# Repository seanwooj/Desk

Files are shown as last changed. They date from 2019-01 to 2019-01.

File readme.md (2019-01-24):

# Objectives
To make a desk using the CNC knowledge and tactics of OpenDesk
This means:
- Open source
- Modular
- Parametrically designed
- Fabricatable anywhere

# Links
- [Studio Desk](https://www.opendesk.cc/lean/studio-desk#get-it-made)
- [OpenDesk Design Guidelines](https://www.opendesk.cc/playbook/community-resources/designer-onboarding/design-guidelines)
- [OpenDesk Community Forum](https://groups.google.com/forum/#!forum/opendesk-community)
- [Studio Desk Maker Guide](https://github.com/opendesk/design-playground/blob/gh-pages/opendesk-studio-desk/160323_Studio_Desk_Maker_Guide.pdf)
- [OpenDesk Design Playground](https://github.com/opendesk/design-playground/)

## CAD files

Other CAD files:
Studio Desk Files/LEN_STU_PUB_EXP_W-800_L-1600_C-ST_A-SA_M-AP_cad-1_18.000.dxf

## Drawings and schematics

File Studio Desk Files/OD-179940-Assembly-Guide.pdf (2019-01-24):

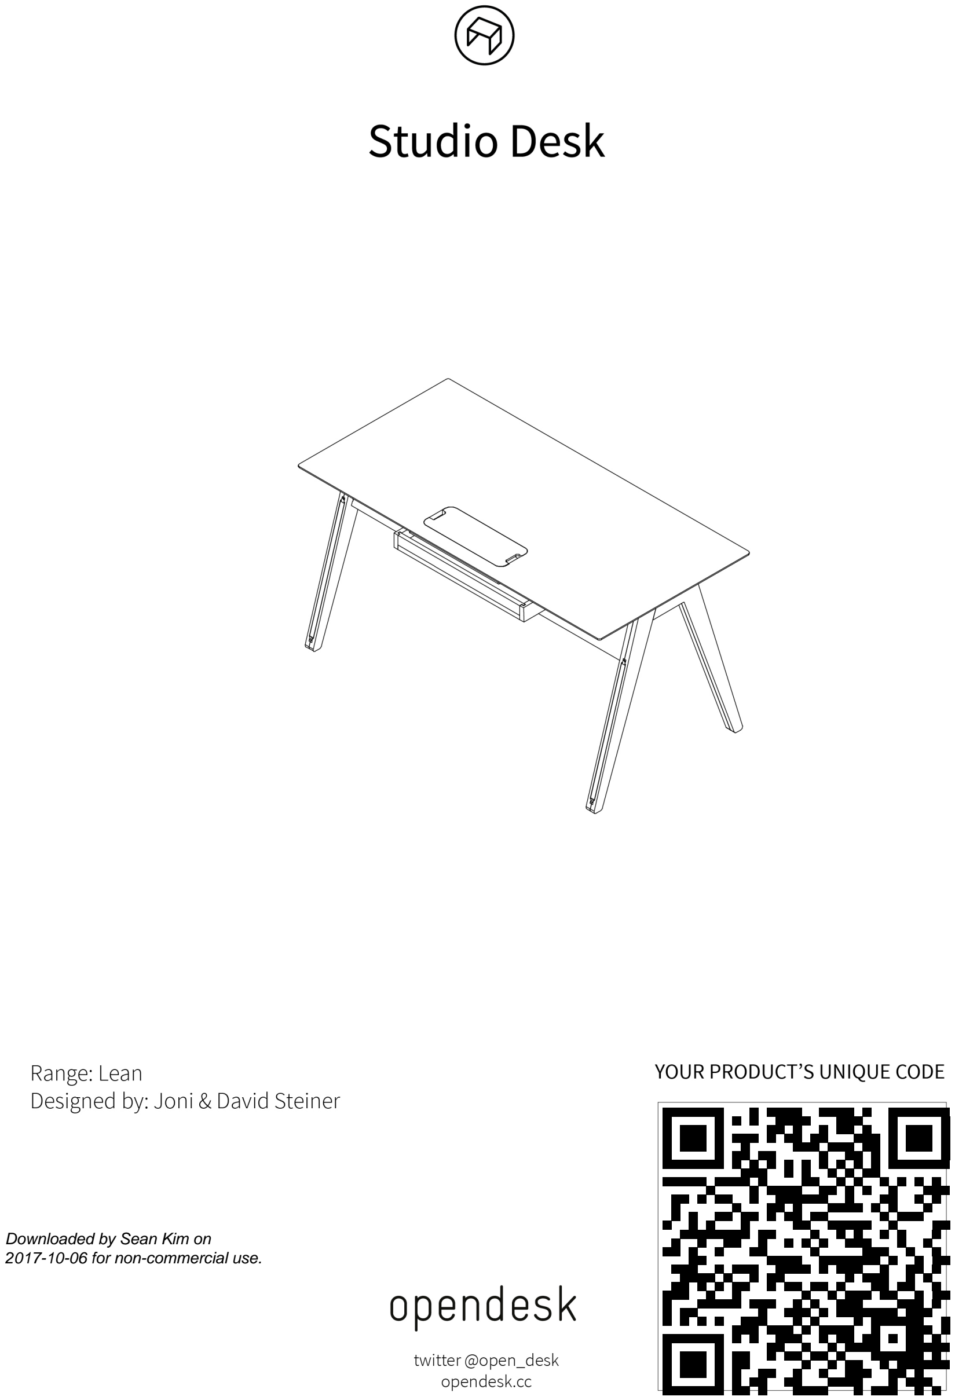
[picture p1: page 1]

Downloaded by Sean Kim on
2017-10-06 for non-commercial use.

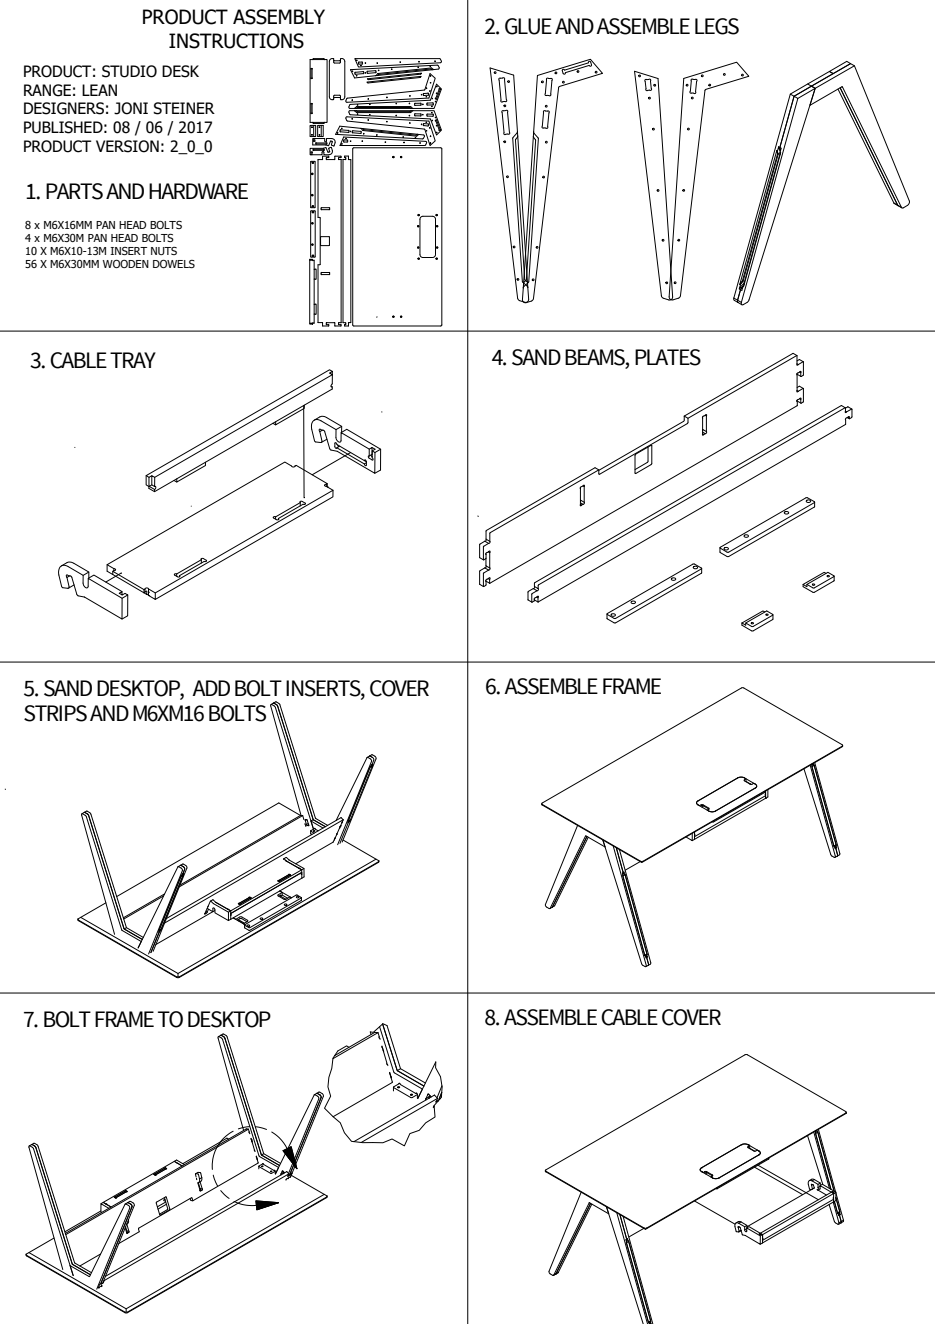
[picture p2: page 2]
2.GLUEANDASSEMBLELEGS; 3. CABLETRAY; 4. SANDBEAMS, PLATES; 5. SANDDESKTOP, ADDBOLTINSERTS, COVER; 6. ASSEMBLEFRAME; STRIPSANDM6XM16BOLTS; 7. BOLTFRAMETODESKTOP; 8. ASSEMBLECABLECOVER; PRODUCT ASSEMBLY INSTRUCTIONS

PRODUCT: STUDIO DESK
RANGE: LEAN
DESIGNERS: JONI STEINER
PUBLISHED: 08 / 06 / 2017
PRODUCT VERSION: 2_0_0
1. PARTSANDHARDWARE

8 x M6X16MM PAN HEAD BOLTS
4 x M6X30M PAN HEAD BOLTS
10 X M6X10-13M INSERT NUTS
56 X M6X30MM WOODEN DOWELS

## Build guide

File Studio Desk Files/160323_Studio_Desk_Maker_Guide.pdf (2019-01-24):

# Studio Desk

# Maker Guide

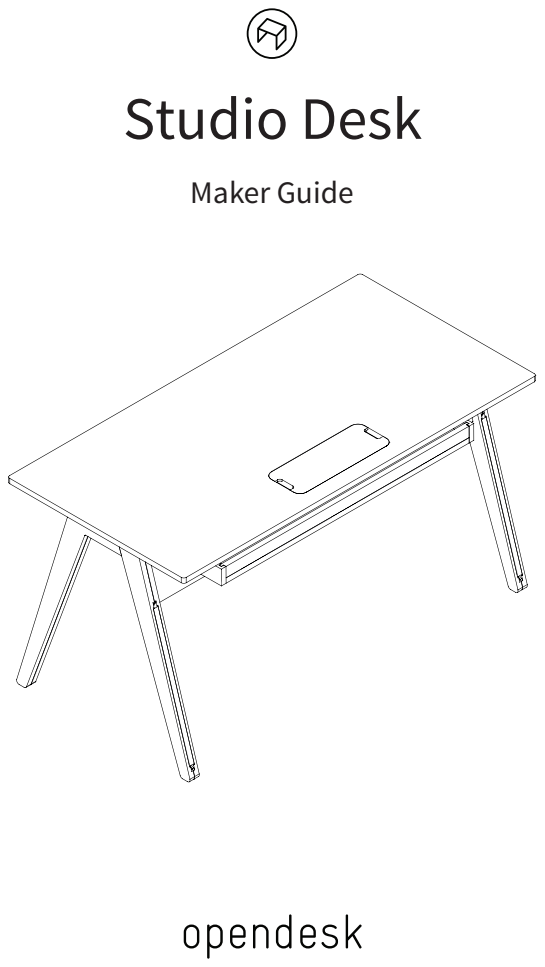
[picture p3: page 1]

# Welcome to your new Opendesk

Every piece of Opendesk furniture is made to order by independent local makers. Opendesk makers produce products on-demand using digital fabricators (CNC- machines) combined with traditional craft skills - working from designs contributed by a global community of designers and hosted on opendesk.cc.

The product you have in your hands is therefore the result of a new model sitting at the union of the internet, new advancements in digital technologies, and age-old making techniques. We call this Open Making.

# Tools

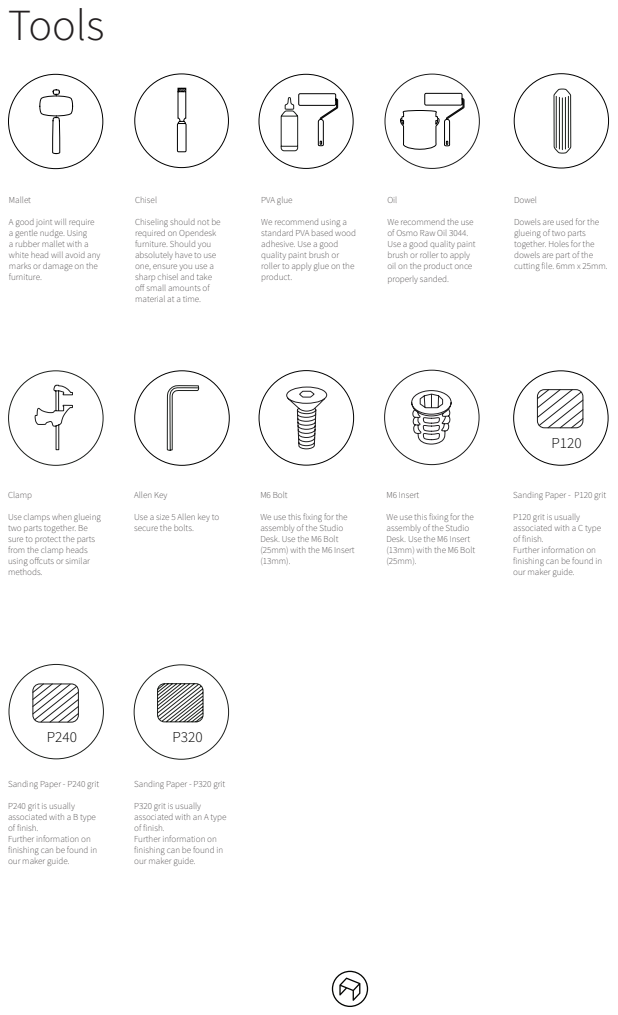
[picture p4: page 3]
Mallet; Chisel; PVA glue; Oil; Dowel; Clamp; Allen Key; M6 Bolt; M6 Insert

A good joint will require
a gentle nudge. Using
a rubber mallet with a
white head will avoid any
marks or damage on the
furniture.

Chiseling should not be
required on Opendesk
furniture. Should you
absolutely have to use
one, ensure you use a
sharp chisel and take
off small amounts of
material at a time.

We recommend using a
standard PVA based wood
adhesive. Use a good
quality paint brush or
roller to apply glue on the
product.

We recommend the use
of Osmo Raw Oil 3044.
Use a good quality paint
brush or roller to apply
oil on the product once
properly sanded.

Dowels are used for the
glueing of two parts
together. Holes for the
dowels are part of the
cutting file. 6mm x 25mm.

Sanding Paper - P120 grit

Use clamps when glueing
two parts together. Be
sure to protect the parts
from the clamp heads
using offcuts or similar
methods.

Use a size 5 Allen key to
secure the bolts.

We use this fixing for the
assembly of the Studio
Desk. Use the M6 Bolt
(25mm) with the M6 Insert

Desk. Use the M6 Insert
(13mm) with the M6 Bolt

P120 grit is usually
associated with a C type
of finish.
Further information on
finishing can be found in
our maker guide.

Sanding Paper - P240 grit

Sanding Paper - P320 grit

P240 grit is usually
associated with a B type

P320 grit is usually
associated with an A type

# Type of fit

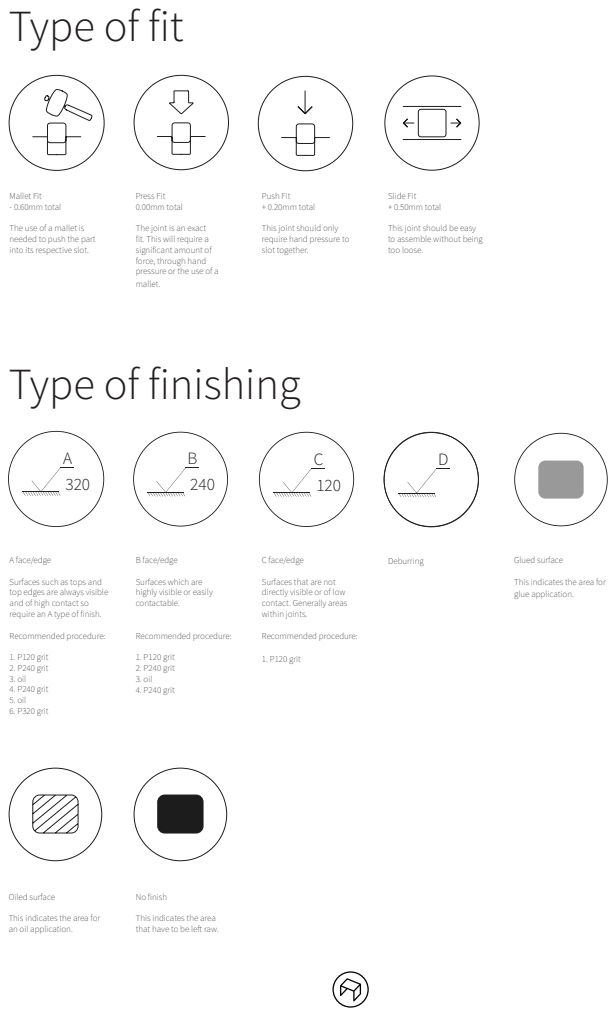
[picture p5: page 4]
Mallet Fit - 0.60mm total; Press Fit 0.00mm total; Push Fit + 0.20mm total; Slide Fit + 0.50mm total; A face/edge; Recommended procedure:; 1. P120 grit 2. P240 grit 3. oil 4. P240 grit 5. oil 6. P320 grit; B face/edge; 1. P120 grit 2. P240 grit 3. oil 4. P240 grit; C face/edge; 1. P120 grit; Deburring; Glued surface; Oiled surface; No finish

The use of a mallet is
needed to push the part
into its respective slot.

The joint is an exact
fit. This will require a
significant amount of
force, through hand
pressure or the use of a
mallet.
Type of finishing

This joint should only
require hand pressure to
slot together.

This joint should be easy
to assemble without being
too loose.

Surfaces such as tops and
top edges are always visible
and of high contact so
require an A type of finish.

Surfaces which are
highly visible or easily
contactable.

Surfaces that are not
directly visible or of low
contact. Generally areas
within joints.

This indicates the area for
glue application.

an oil application.

This indicates the area
that have to be left raw.

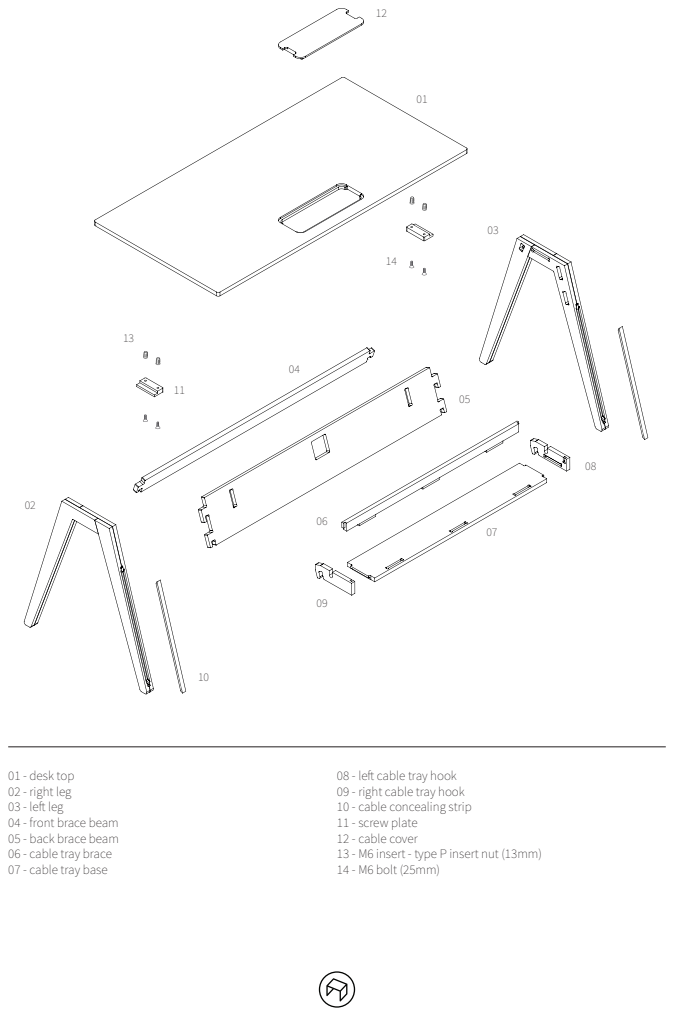
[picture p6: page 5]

01 - desk top
02 - right leg
03 - left leg
04 - front brace beam
05 - back brace beam
06 - cable tray brace
07 - cable tray base

08 - left cable tray hook
09 - right cable tray hook
10 - cable concealing strip
11 - screw plate
12 - cable cover
13 - M6 insert - type P insert nut (13mm)
14 - M6 bolt (25mm)

# Suggested Method

Parts:

1x Table top
1x Cable cover
1x Brace beam front
1x Brace beam back
1x Cable tray back
1x Cable tray base
2x Cable tray sides
2x Leg A (L+R)
2x Leg B (L+R)
2x Leg C (L+R)
2x Leg D (L+R)
2x Screw plates
2x Leg cable concealing strips 4x M6 Inserts and bolts
28x Dowels, 6x25mm

Standard Steps:

1. Assemble, sand, oil legs
2. Sand, oil, assemble cable tray
3. Sand and oil all plates and beams
4. Sand and oil table top and cable cover
5. Assemble

Instructions:

1. Spread one side of leg parts out on the workbench in order BCDA. Dab a drop of glue in each of the C and D holes and add the dowels. With a roller spread the glue evenly on the B and A faces. Join together BC and DA, then join these two sets together, BCDA. When bringing the legs together, C and A will overlap at the top. Sandwich the legs together and bang to close the gap with a mallet. Check that the gap is closed up and flush. Repeat the whole process on the right side leg. With Grit 240 individually sand each set of legs. Sand all the ply edges first and then the facings. Oil in the same order. Wipe off any excess and put to the side. Sand the two leg cable cover inserts with 240, then oil, wipe dry and check that they fit tight into the back of the legs. Once finish, put legs, with cover inserts to the side.
2. Sand the ply edge of the two side pieces for the cable tray together, then the faces, with grit 240. Oil, then wipe dry. Do the same with the base of the cable tray, then the back. Glue up all pockets and assemble the back to the base then add the two sides. Put to one side, or under the workbench.

# Suggested Method

3. Sand the plates with grit 240. Sand the edge grain first on both long sides, then the faces. Oil in the same order you sanded, however avoid getting oil on one end of the plates to allow for glue. Wipe off any excess oil. Repeat the process with the two brace beams. Put parts to side.
4. Sand the cable cover around the edge then the faces with Grit 400, Oil, wipe dry and put to the side. Make sure the workbench is completely wiped down and free of debris. Place table top on the workbench length-ways but up on its edge. Using 240, sand around the plywood edge first in an ‘L’ formation, rotating the table top so the sanding pressure is always facing down where possible. Make sure chamfers are also sanded smoothly. Laying the table top upside down, sand the underside with 400. Hand sand the rim of the cable cover hole with 240 grit. Oil the whole underside evenly with a roller then wipe dry. Flip the top over and sand with 400. Oil the edge and the top, wipe down any excess. Flip the top over again, add the inserts to all 4 holes.
5. Place the table top upside down on the workbench. Insert the brace bars into one set of legs, the larger bar goes onto the leg with the cable slot in the back. Force them down so they are flush with the top of the leg. Do the same process with the other set of legs, you now have your frame. Flip the frame over onto the table top and align the insert holes. With an allen key turn the bolts until tight in the hole.

Standard Checks:

1. Flip over the table onto the floor and test for rigidity.
2. Make sure the rim and chamfer around the tabletop is smooth to the touch.
3. Check the inserts and bolts are fully locked in place.

Standard Estimated Timings:

1. Assemble, sand, oil legs | A-5.5, S-14, O-3.5 | 24 min
2. Sand, oil, assemble cable tray | S-5, O-2, A-2 | 9 min
3. Sand, oil plates and beams | S-7, O-3 | 10 min
4. Sand and oil tabletop with cable cover | S-19, O-7 A-1 | 27 min
5. Assemble | A-3 | 3-5 min
Estimated Total: | | 73 min

# Cutting Sheet

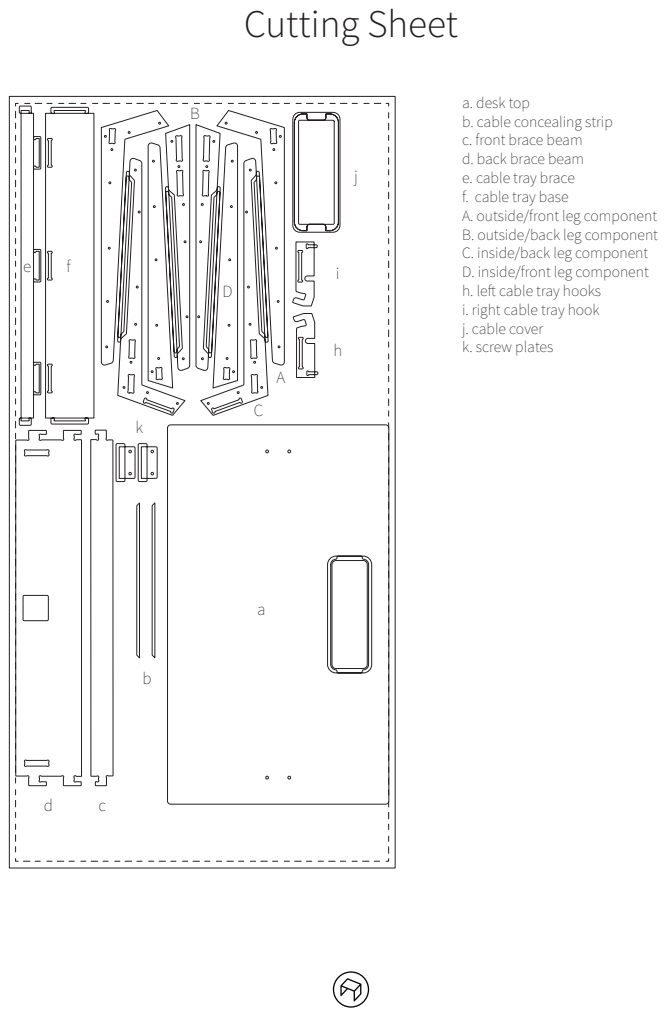
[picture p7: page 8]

a. desk top
b. cable concealing strip
c. front brace beam
d. back brace beam
e. cable tray brace
f. cable tray base
A. outside/front leg component
B. outside/back leg component
C. inside/back leg component
D. inside/front leg component
h. left cable tray hooks
i. right cable tray hook
j. cable cover
k. screw plates

# Components

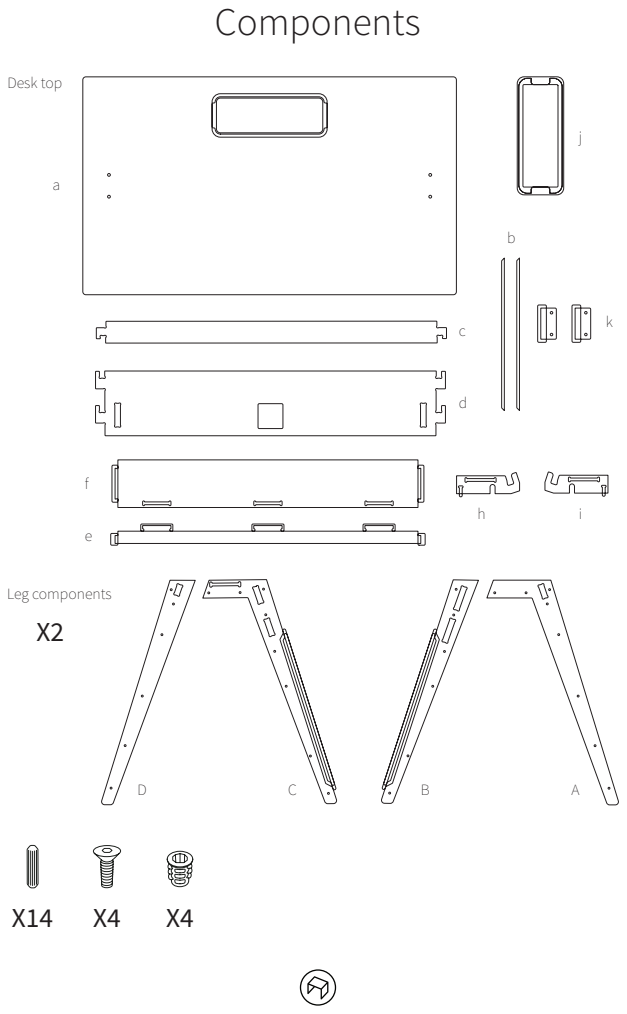
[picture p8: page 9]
Leg components; Desk top

# Leg Exploded

X14

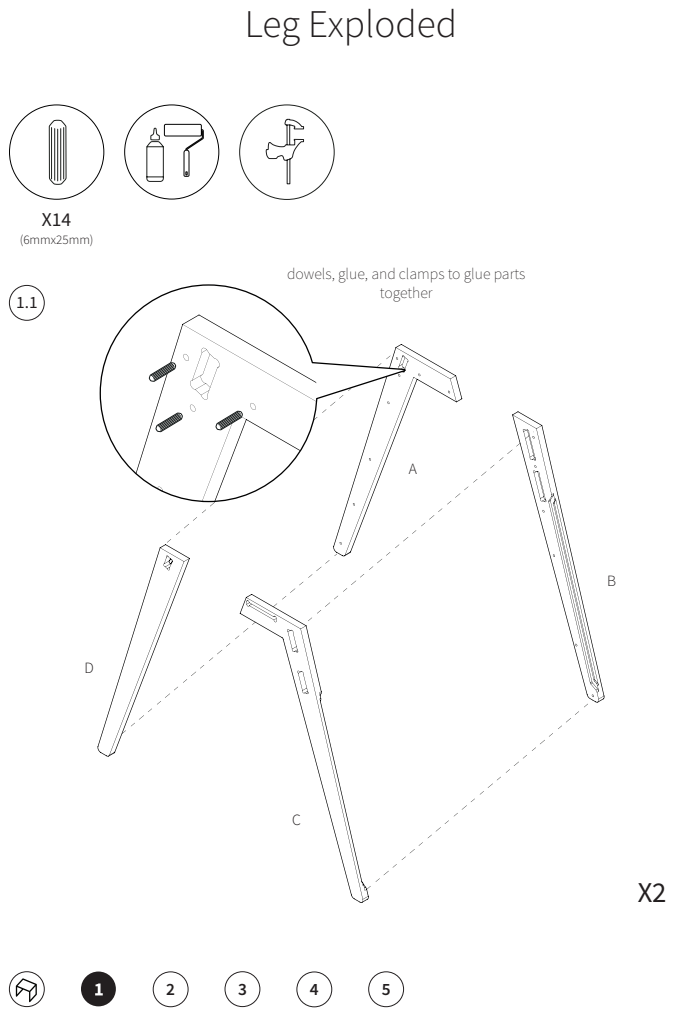
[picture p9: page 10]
(6mmx25mm); together

dowels, glue, and clamps to glue parts

# Leg Exploded

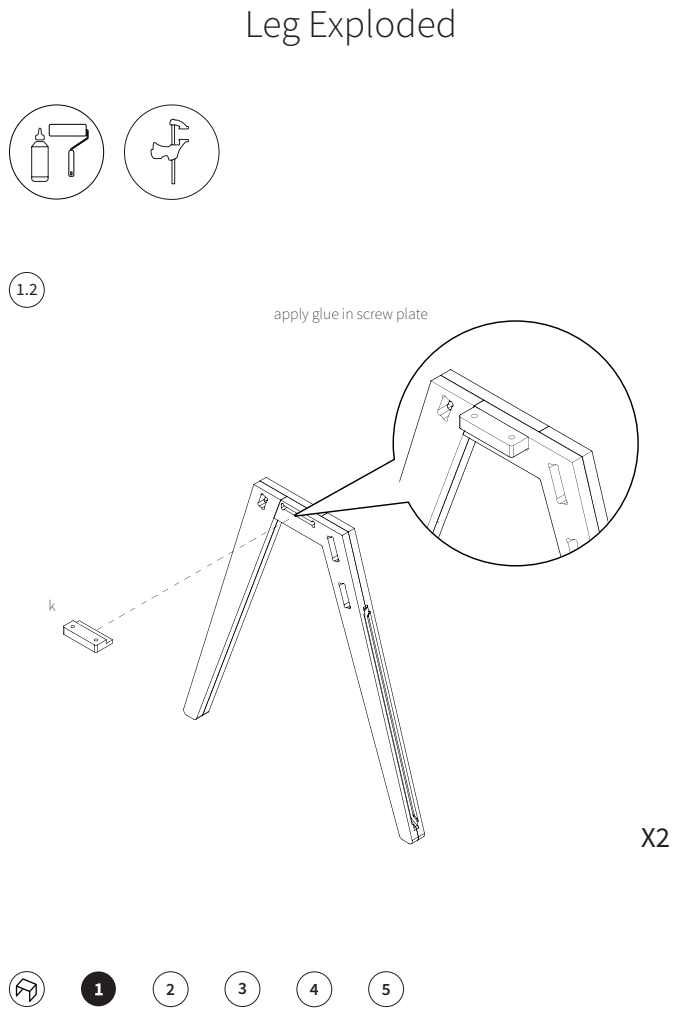
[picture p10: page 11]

apply glue in screw plate

# Complete Leg

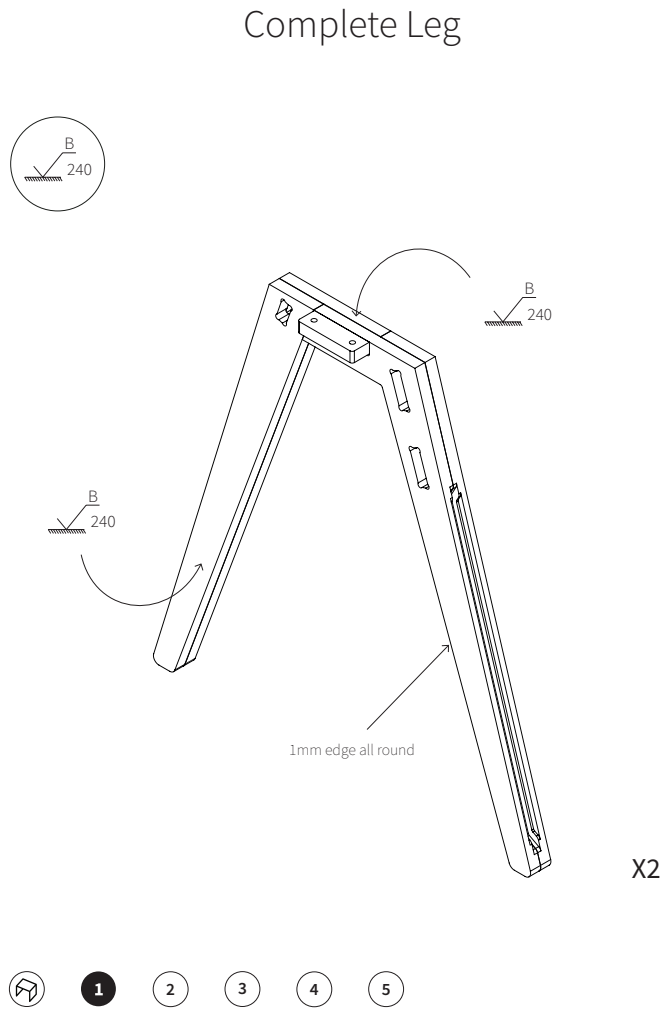
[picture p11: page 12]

1mm edge all round

# Table Top

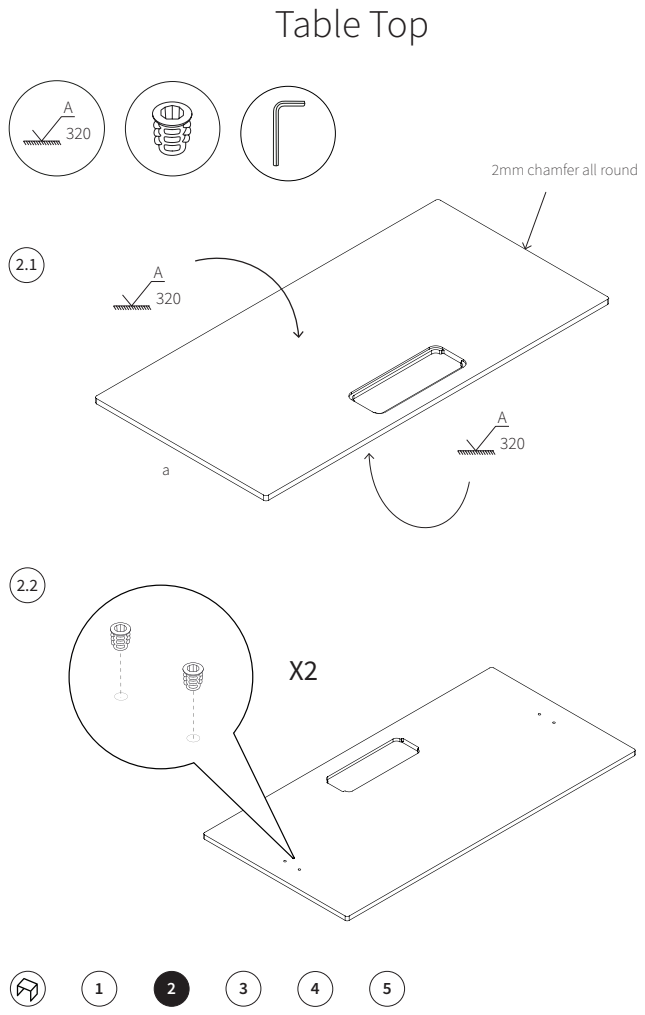
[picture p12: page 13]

2mm chamfer all round

# Brace Beams

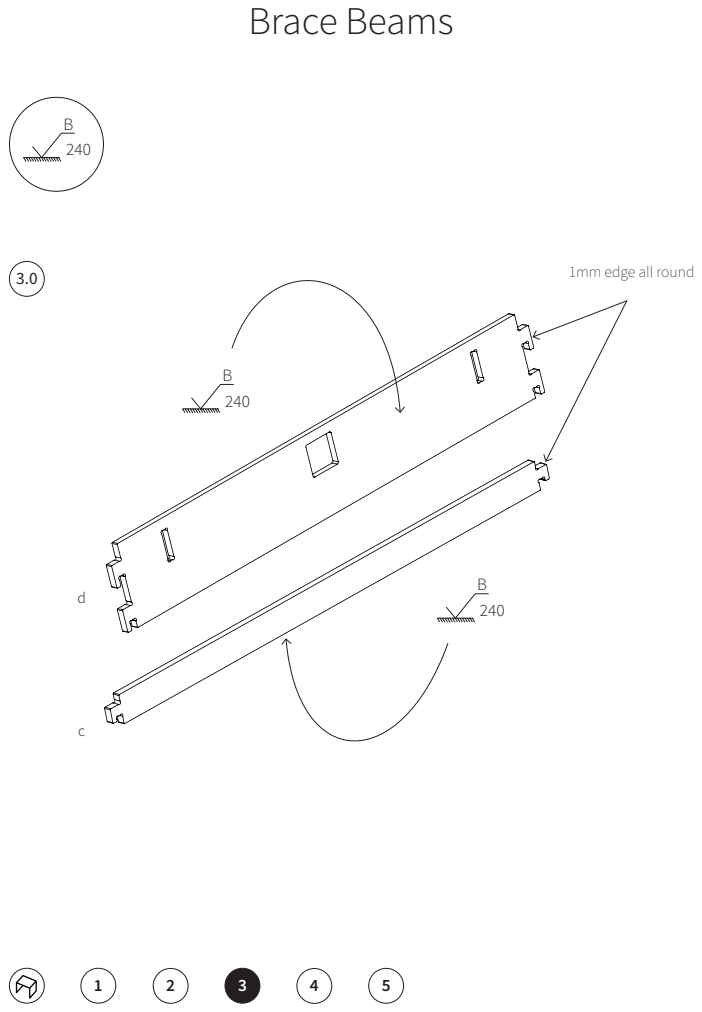
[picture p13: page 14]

1mm edge all round

# Cable Tray Parts

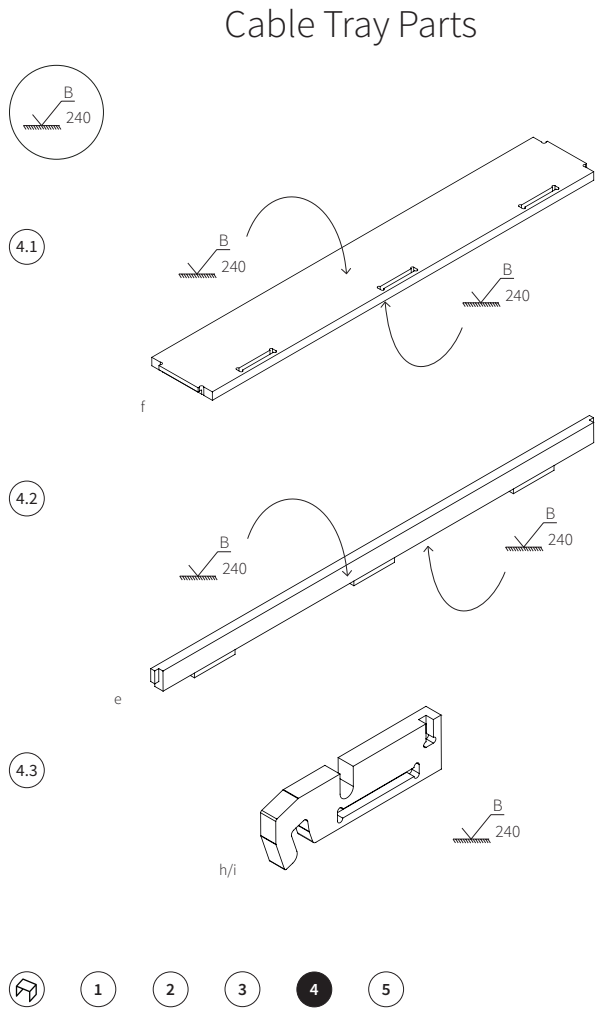
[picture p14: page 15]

# Cable Tray Exploded

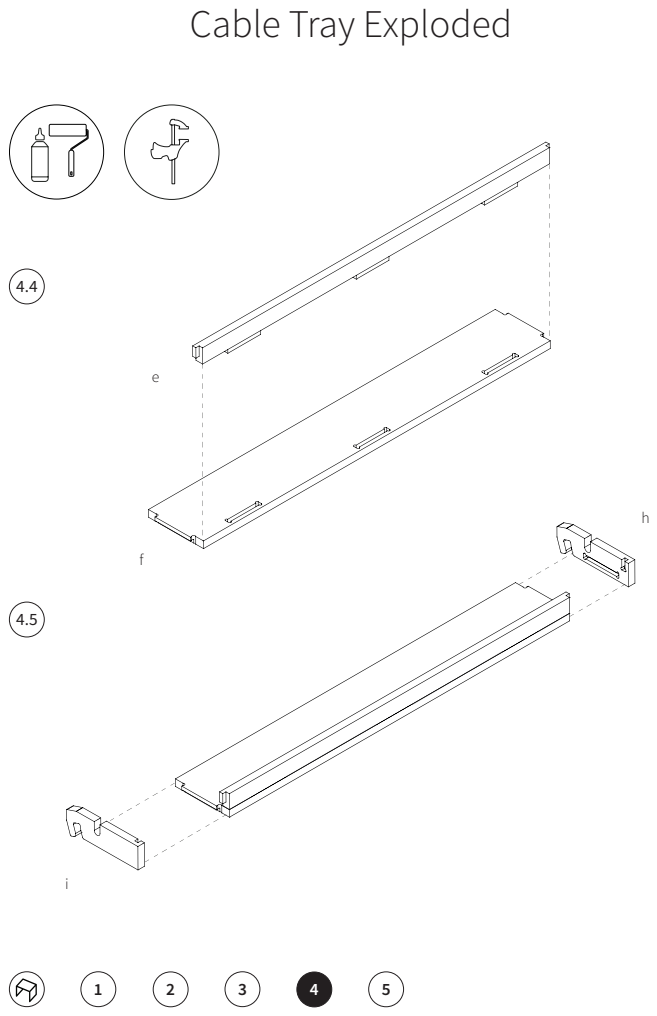
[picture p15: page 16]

# Completed Cable Tray

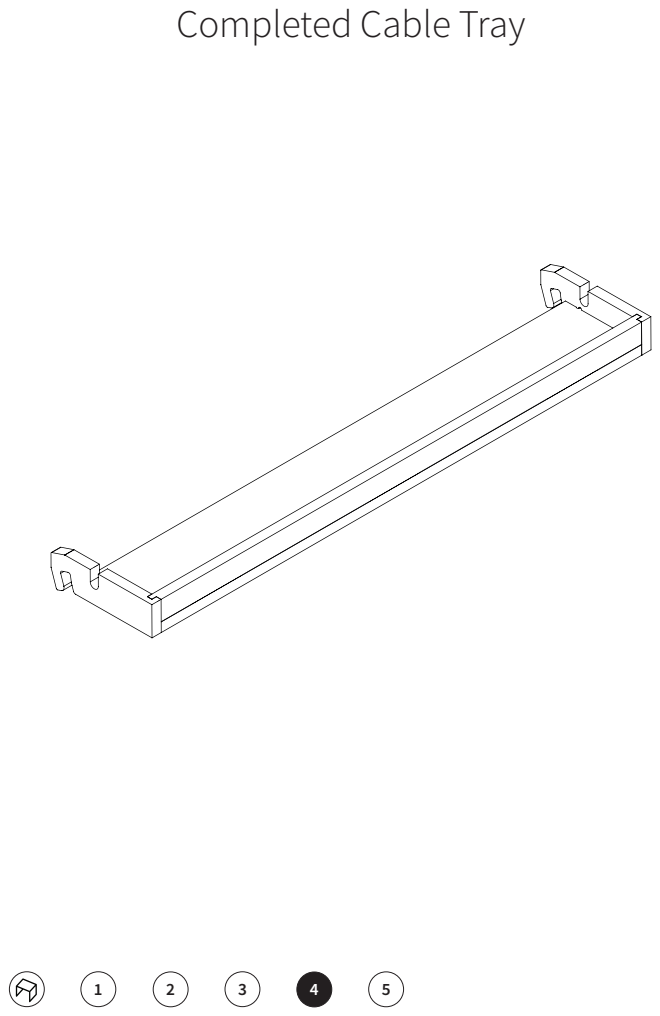
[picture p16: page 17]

# Cable Cover and Cable Concealing Strips

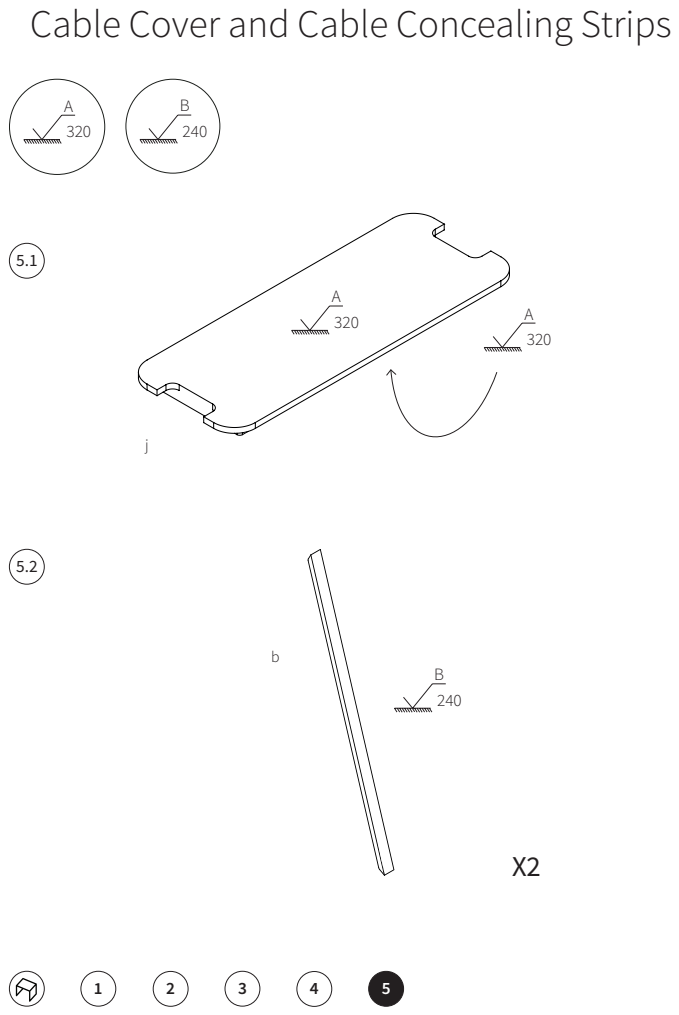
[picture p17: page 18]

# Checklist for Assembly

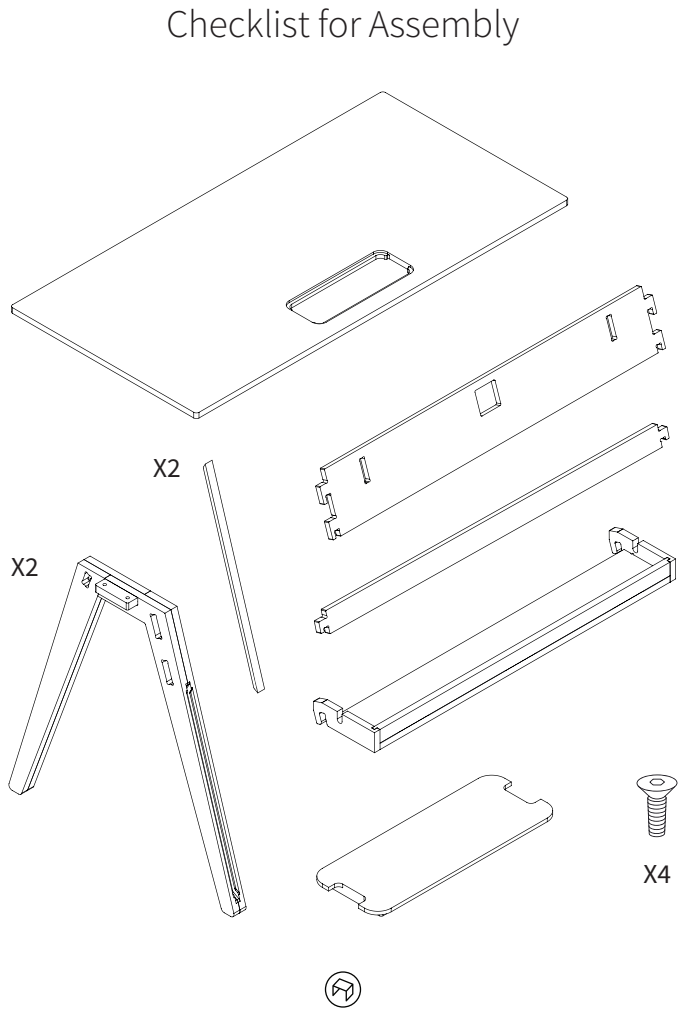
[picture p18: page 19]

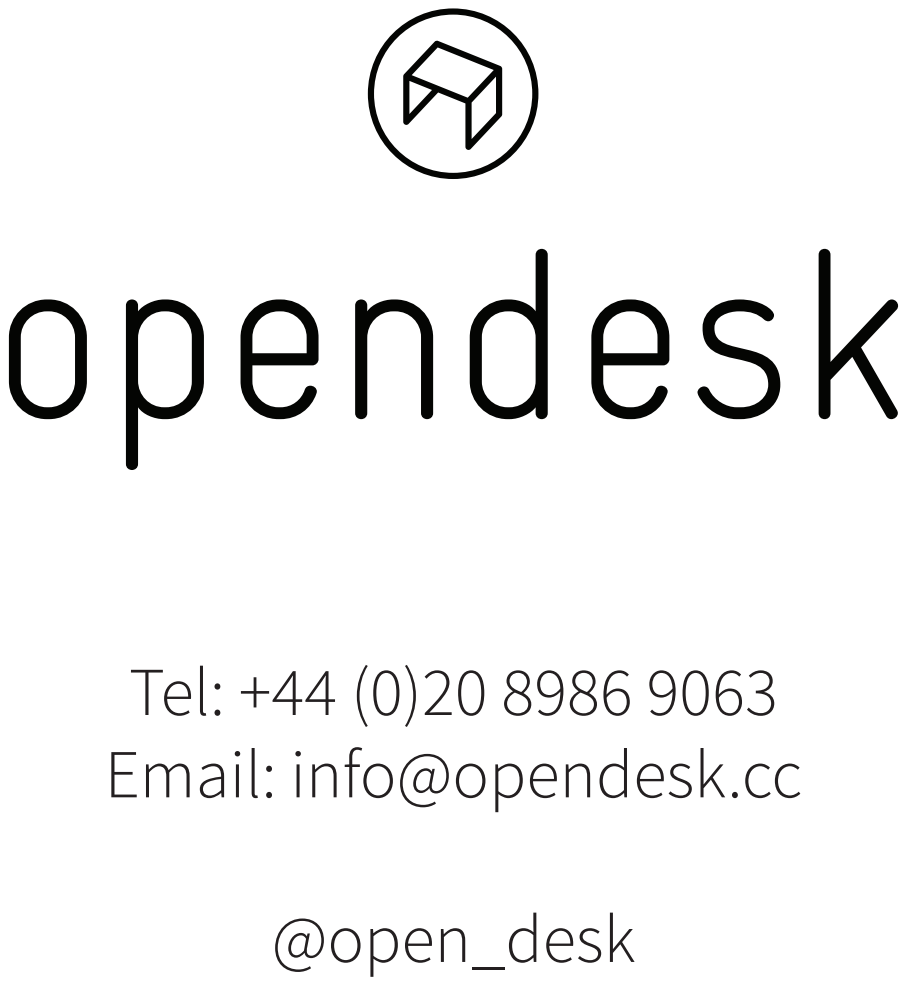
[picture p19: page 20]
@open_desk

Tel: +44 (0)20 8986 9063
Email: info@opendesk.cc
